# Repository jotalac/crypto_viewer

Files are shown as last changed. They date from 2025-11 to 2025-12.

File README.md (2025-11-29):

# Crypto Price Viewer
show show

DIY cryptocurrency price dispaly.

## Description

This project is diy simple **cryptocurrency price viewer**. It fetches real-time data from a cryptocurrency API and displays it on a screen. The device is housed in a 3D-printed case with colored screen.

This is a standalone device that is not dependent on your computer.

## Features

*   **Price Tracking:** Fetches and displays up-to-date cryptocurrency prices.
*   **Display:** Shows data on 240x320px screen.
*   **Button Controls:** Navigate through different cryptocurrencies.
*   **Buzzer:** Provides audible alerts.
*   **3D-Printed Case:** A custom-designed case to house all the components.
*   **Configurable from phone:** Connect to AP and configure the device from your phone.
*   **Wi-Fi Connectivity:** Connects to your local network to access the internet.

## Hardware

This project uses the following hardware components:

*   **Microcontroller:** XIAO ESP32C6
*   **Display:** 2inch 240x320px TFT Display: 
*   **Buttons:** 2x - 12x12mm tactile switch (B3F-4055)
*   **Buzzer (optional):** buzzer without generator
*   **Antenna (optional, for better signal):** mini antenna with uFL connector
*   **Perfboard:** prefboard 30x70 mm
*   **Cables and wires**
*   **3D printed case:** 3d printed parts, in the model folder
*   **Screws:** 2x 2.5x20mm screw (for case assembly)

#### Hardware links
- Dispaly (~3.0$)
    - https://www.aliexpress.com/item/1005006589727895.html?spm=a2g0o.order_list.order_list_main.11.757d1802qw4zkG
- Microcontroller (~8.0$, get from your local supplier)
    - https://botland.cz/moduly-wifi-a-bt-esp32/24783-seeed-xiao-esp32-c6-wifi-bluetooth-seeedstudio-113991254-5904422385705.html
- Tactile switches (~0.5$):
    - https://makershop.ie/B3F4055?srsltid=AfmBOooik3h_e8dq_zdSf28YTv6m92bTonL3PdaJR46RWWBAH6ENf9dU
- Buzzer (~2.0$):
    - https://botland.store/buzzers-sound-generators/4187-buzzer-without-generator-23mm-1-40v-in-a-case-5904422366070.html
- Antenna (~2$)
    - https://botland.store/wifi-antennas/13810-mini-flexible-wifi-antenna-24ghz-with-ufl-connector-100mm-5904422321505.html
- Perfboard (~0.5$)
    - https://www.amazon.com/Fielect-Electronic-Protoboard-Prototyping-Printed/dp/B081Q4XH7Z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
- 3D printed case
    - https://github.com/jotalac/crypto_viewer/tree/main/model

## Usage guide
### Setup
*   After first connection you will se this screen


*   Connect to that wifi from your phone, and this setup screen will popup
  


*   Select configue wifi
*   Select your wifi ssid and fill in the password
*   Below you can set up to 3 cryptocurrencies to be displayed on your display
*   Hit save

## Usage
*   Price refreshes once in 10 minutes for the currently displayed coin 
    *   you can chagne the interval in the code
    *   don't make the interval too short, because you might hit the rate limit of the api

*   **Left button press** - go to next coin
*   **Left button hold** - fetches new price, for the currently displayed coin
*   **Right button press** - reset the device
*   **Right button hold** - enter config mode

## Software

The firmware is written in C++ using the Arduino framework.

### Libraries

*   TFT_eSPI - by Bodmer
*   ArduinoHttpClient
*   ArduinoJson
*   WiFiManager
*   Preferences - by Volodymyr Shymanskyy

## Assembly Guide

### Step 1: Setup arduino ide
- add xiao esp32c6 support for the arduino ide
    - guide: https://wiki.seeedstudio.com/xiao_esp32c6_getting_started/
- downlaod listed libraries
- find this path on you computer: **Arduino/libraries/TFT_eSPI/User_Setup.h**
    - paste this to the user setup file:
    ```bash
    #define USER_SETUP_INFO "User_Setup"
    #define ST7789_2_DRIVER
    #define TFT_SDA_READ   
    #define TFT_RGB_ORDER TFT_RGB  // Colour order Red-Green-Blue

    #define TFT_WIDTH  240 
    #define TFT_HEIGHT 320

    #define TFT_MOSI 18  
    #define TFT_SCLK 19  
    #define TFT_CS   22  
    #define TFT_DC   21  
    #define TFT_RST  23  

    #define LOAD_GLCD   // Font 1. Original Adafruit 8 pixel font needs ~1820 bytes in FLASH
    #define LOAD_FONT2  // Font 2. Small 16 pixel high font, needs ~3534 bytes in FLASH, 96 characters
    #define LOAD_FONT4  // Font 4. Medium 26 pixel high font, needs ~5848 bytes in FLASH, 96 characters
    #define LOAD_FONT6  // Font 6. Large 48 pixel font, needs ~2666 bytes in FLASH, only characters 1234567890:-.apm
    #define LOAD_FONT7  // Font 7. 7 segment 48 pixel font, needs ~2438 bytes in FLASH, only characters 1234567890:-.
    #define LOAD_FONT8  // Font 8. Large 75 pixel font needs ~3256 bytes in FLASH, only characters 1234567890:-.
    #define LOAD_GFXFF  // FreeFonts. Include access to the 48 Adafruit_GFX free fonts FF1 to FF48 and custom fonts
    #define SMOOTH_FONT

    #define SPI_FREQUENCY  27000000
    #define SPI_READ_FREQUENCY  20000000
    #define SPI_TOUCH_FREQUENCY  2500000
    ``` 
### Step 2: Soldering components 
*   Solder controller on the prefboard (9 pins availible left, 8 pin availible on right)
*   Solder display
*   Solder buzzer
*   Put the antenna on the controller port
*   Don't solder the buttons just yet

*  *solder the components according to the wiring diagram and tables*

### Wiring

diagram
diagram2

**Display**

| From (Display) | To (ESP32C6) |
| --- | --- |
| GND | GND |
| VCC | 3V3 |
| SCL | D8 (GPIO19) |
| SDA | D10 (GPIO18) |
| RST | D5 (GPIO23) |
| DC |  D3 (GPIO21) |
| CS |  D4 (GPIO22) |

**Buttons**
- leg orientation doesnt matter (but make sure to solder the opposite legs)

| From (Button) | To (ESP32C6) |
| --- | --- |
| left btn - 1. leg | D1 (GPIO1) |
| left btn - 2. leg | GND |
| |  |
| right btn - 1. leg | D2 (GPIO2) |
| right btn - 2. leg | GND |

**Buzzer**

| From (Buzzer) | To (ESP32C6) |
| --- | --- |
| red cable | D0 (GPIO0) |
| black cable | GND |

### Step 3: 3D Printing

*   Print the case and button caps
*   You can choose the version with holes (much cooler) or the normal one without holes

### Step 4: Final Assembly

*   Put the buttons with caps into the holes on top of the case
*   Now solder the buttons according to the prefboard according to the diagram   
*   Slide the prefboard into the case and put in the antenna and buzzer
*   Put in the 2 screws to hold the two parts of the case together

### Step 5: Software flashing

*   Connect the board to your pc
*   Clone this repository
*   In Arduino IDE open the `code.ino` file
*   Make sure you have installed all the libraries and edited the `User_Setup.h` file
*   Click the upload button in the arduino ide to compile and flash the firmware
    * The ide might tell you that you have run out of memeory on the board
        *   go to: `Tools->Partition Scheme` and select `Huge APP`

## Contributing

- Contributions are welcome! Please feel free to submit a pull request.
- Adding new features is very welcome.

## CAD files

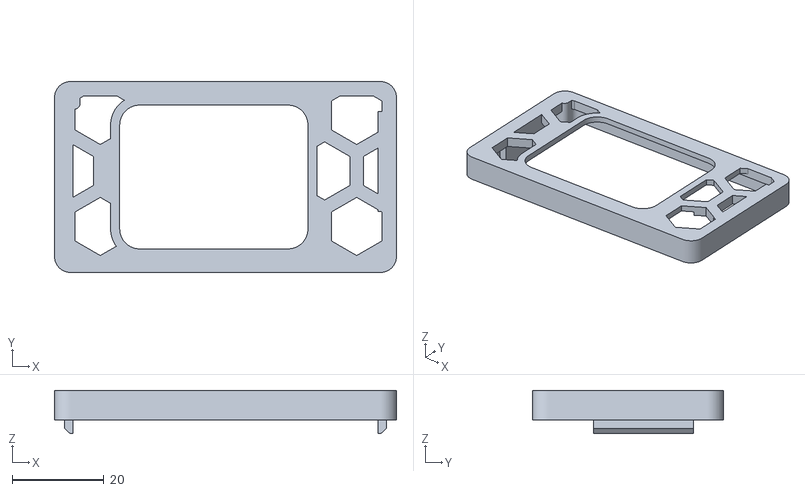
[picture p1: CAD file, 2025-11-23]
model/holes/front-holes.stl
74.7 x 41.7 x 9.50

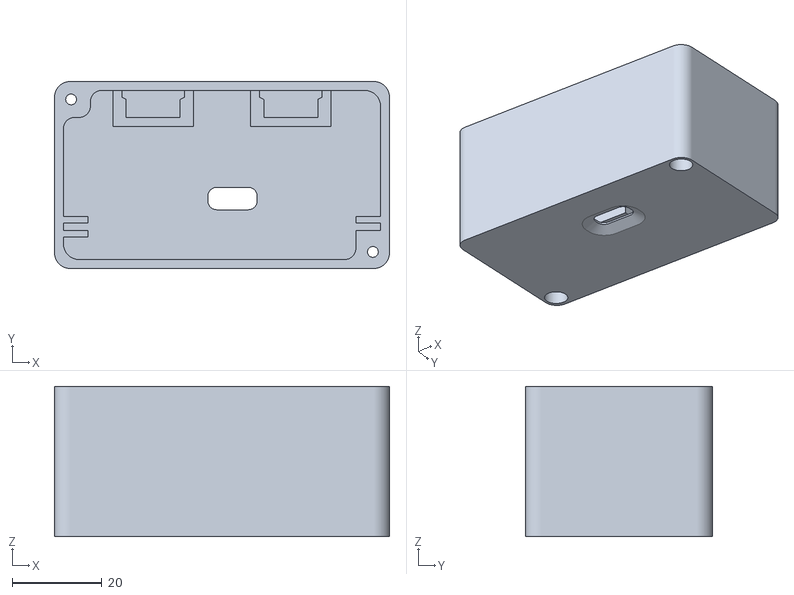
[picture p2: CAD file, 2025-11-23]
model/normal/back.stl
74.7 x 41.7 x 33.5

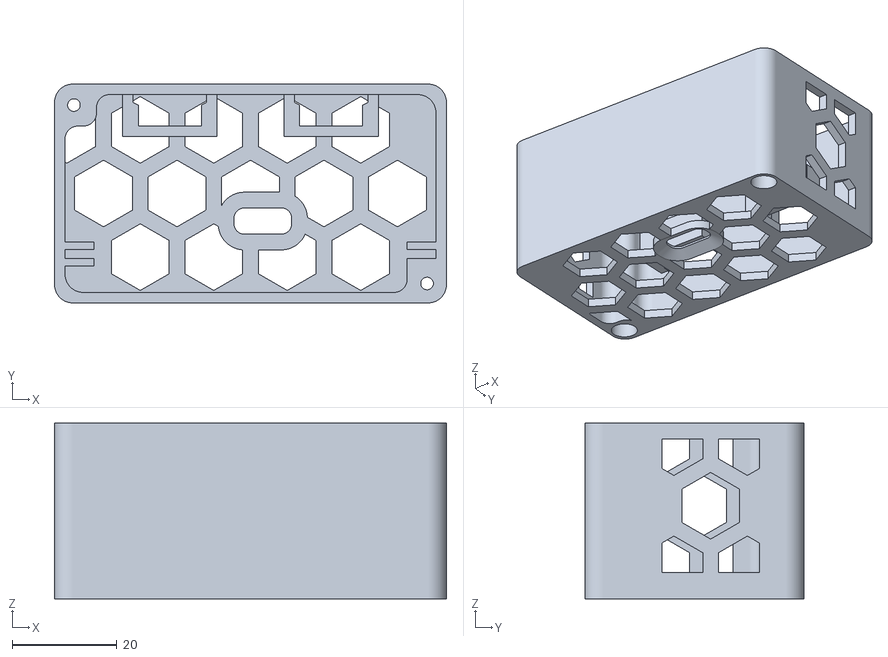
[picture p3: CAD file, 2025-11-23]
model/holes/back-holes.stl
74.7 x 41.7 x 33.5

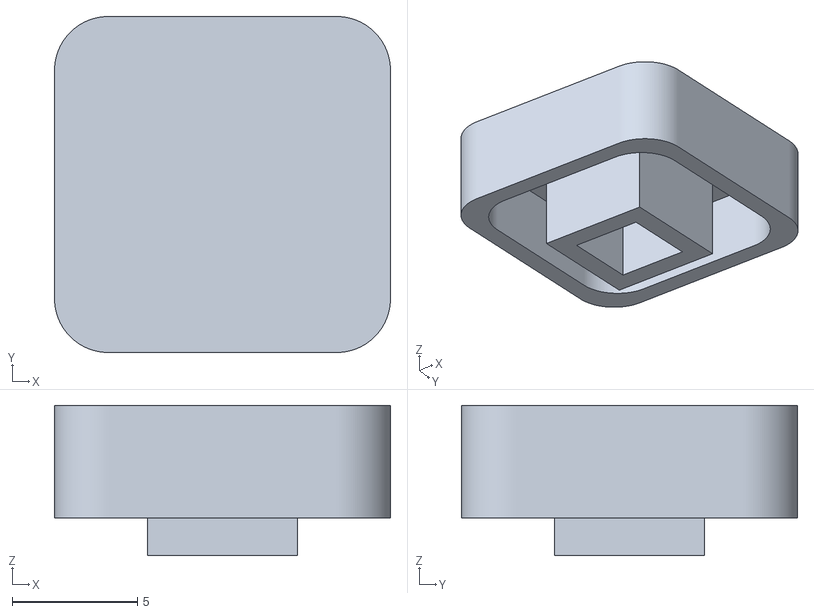
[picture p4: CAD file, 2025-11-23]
model/normal/button-simple.stl
13.4 x 13.4 x 6.00

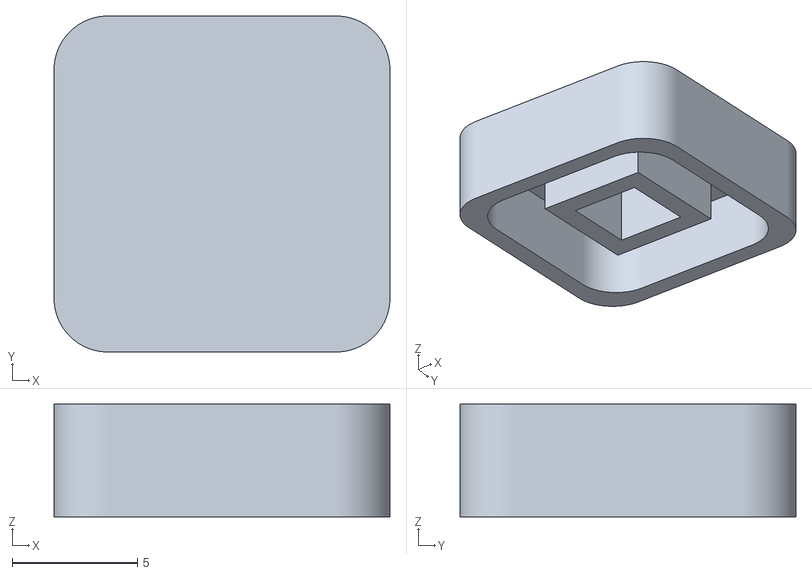
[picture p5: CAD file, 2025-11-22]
model/holes/button-simple.stl
13.4 x 13.4 x 4.50

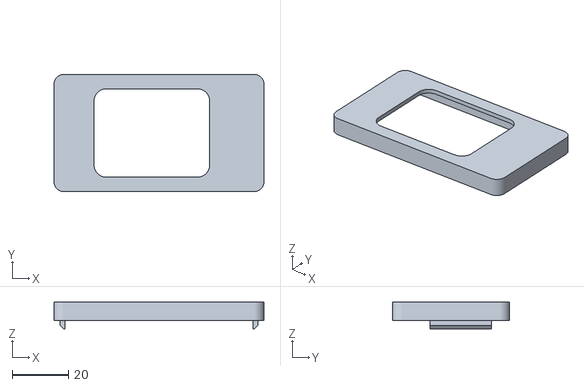
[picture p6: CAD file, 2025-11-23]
model/normal/front.stl
74.7 x 41.7 x 9.50

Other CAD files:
model/step/front.step
model/step/back.step

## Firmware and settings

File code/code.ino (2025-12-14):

#include "config.h"
#include "wifi_config.h"
#include "network.h"
#include "display.h"
#include "utils.h"
#include "buzzer.h"
#include "button_control.h"

unsigned long last_fetch_time = 0;
const unsigned long FETCH_INTERVAL = 1000 * 60 * 10;  // 10 minutes
const unsigned long FETCH_GRAPH_INTERVAL = 1000 * 60 * 60;  // 1 hour
CoinData all_coins_data[3] = {{}, {}, {}};
GraphData all_graph_data[3] = {{}, {}, {}};
int total_screens = 0;

void setup() {
  Serial.begin(9600);

  total_screens = get_screen_count();

  // setup buttons and anthena  pins
  pinMode(BUTTON_COIN_PIN, INPUT_PULLUP);
  pinMode(BUTTON_CONFIG_PIN, INPUT_PULLUP);
  pinMode(BUZZER_PIN, OUTPUT);

  turn_on_external_antenna();

  tft.init();
  tft.setRotation(1);
  tft.setSwapBytes(true);
  
  //setup wifi
  display_message("Connecting...");
  //play boot sound
  play_startup_sound();


  if (!setup_wifi_manager()) {
    display_message("Wifi connection failed");
    delay(2000);
    ESP.restart();
  }

  display_message("Getting current time...");
  setup_time();
}
 
void loop() {  
  //check all button presses
  check_btn_1_press();
  check_btn1_hold();

  check_btn2_press();
  check_btn2_hold();

  //update time;
  events();

  int current_index = get_current_screen_index();

  if (current_index >= total_screens - 1) {
    render_screen_clock();
  }
  else {
    //check if we should fetch new data
    unsigned long current_time = millis();
    if (current_time - last_fetch_time >= FETCH_INTERVAL || last_fetch_time == 0) {
      Serial.println("Fetching new price...");
  
      //check if wifi is connected
      if (!check_wifi_connection()) {
        display_message("Wifi reconnect failed, Restarting...");
        delay(2000);
        ESP.restart();
      };
  
      int current_coin_index = get_current_screen_index();
  
      //fetch coin data
      CoinData fetched_data = fetch_coin_data();
  
      //check if we need to fetch new grapth (every 1 hour)
      GraphData graph_data = all_graph_data[current_coin_index]; 
      if ((current_time - graph_data.last_fetch >= FETCH_GRAPH_INTERVAL || graph_data.last_fetch == 0) && should_display_graph()) {
        graph_data = fetch_graph_data();
        all_graph_data[current_coin_index] = graph_data;
      }
  
      if (fetched_data.price != -1) {
        //display new data
        render_screen(fetched_data, graph_data, "*24h");
        last_fetch_time = current_time;
        //update the saved vlaues
        all_coins_data[current_coin_index] = fetched_data;
        //play sound if the current price is ath
        if (fetched_data.ath_percentage >= 0) play_ath_sound();
      } else {
        display_message("Fetch error for: " + get_coin_name());
        // Retry in 30 seconds instead of 10 minutes on error
        last_fetch_time = current_time - FETCH_INTERVAL + 30000;
      }
    }
  }

  delay(100);
}

void check_btn_1_press() {
  if (check_screen_change_button()) {    
      //try to go to next coin if only one coin is setup dont do anything
      if (go_to_next_screen()) {
        Serial.println("Cycling to next screen");  
        
        int current_index = get_current_screen_index();
        
        // Determine name for display
        String name_to_show;
        if (current_index >= total_screens - 1) {
            name_to_show = "Time";
        } else {
            name_to_show = get_coin_name();
        }

        display_message("Switching to: " + name_to_show);
        delay(500);
        
        if (current_index >= total_screens - 1) {
          //display time
          render_screen_clock();
        }
        // Force immediate fetch for coins
        else {
           // If we have no data yet, force fetch
           if (all_coins_data[current_index].symbol.empty()) {
             last_fetch_time = 0;
           } else {
             render_screen(all_coins_data[current_index], all_graph_data[current_index], "*24h");
           }
        }
      }
  }
}

void check_btn1_hold() {
  if (check_coin_fetch_button()) {    
    Serial.println("Fetching new price");
    display_message("Fetching new price");    
    // Force immediate fetch
    last_fetch_time = 0;
  }
}

void check_btn2_press() {
  if (check_reset_button()) {
    Serial.println("Reseting button pressed");

    display_message("Reseting device");
    delay(1000);
    ESP.restart();
  }
}

void check_btn2_hold() {
  if (check_config_button()) {
    Serial.println("Config mode entered");
    play_config_sound();

    display_wifi_setup_message("Configue");

    if (start_config_portal_on_demand()) {
      display_message("Config saved, restarting...");
      delay(2000);
      ESP.restart(); //restart to apply changes
    } else {
      display_message("Config canceled");
      last_fetch_time = 0; //fetch imidietly
    }
  }
}

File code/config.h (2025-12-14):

#ifndef CONFIG_H
#define CONFIG_H

#include <Arduino.h>
#include <WiFi.h>
#include <WebServer.h>
#include <WiFiManager.h>
#include <HTTPClient.h>
#include <ArduinoJson.h>
#include <Preferences.h>
#include <TFT_eSPI.h>
#include <ezTime.h>
#include <vector>
#include <string>
#include <cstdio>

// extern variables
extern Preferences preferences; 
extern TFT_eSPI tft;
extern Timezone myTZ;

// button
#define PORTAL_TIMEOUT 120 // 2 minutes wait in wifi config mode
#define CONFIG_PRESS_TIME 3000
#define BUTTON_SHORT_PRESS_TIME 50

#define BUTTON_COIN_PIN 1
#define BUTTON_CONFIG_PIN 2

//buzzer
#define BUZZER_PIN 0

//coin cycling
#define MAX_COINS 3

#endif

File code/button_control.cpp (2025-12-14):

#include "config.h"
#include "button_control.h"

//check if button is hold for 3 seconds
bool check_config_button() {
    static unsigned long button_press_start = 0;
    static bool button_was_pressed = false;
    
    bool button_pressed = (digitalRead(BUTTON_CONFIG_PIN) == LOW);
    
    if (button_pressed && !button_was_pressed) {
        // Button just pressed
        button_press_start = millis();
        button_was_pressed = true;
    } 
    else if (!button_pressed && button_was_pressed) {
        // Button released
        button_was_pressed = false;
        button_press_start = 0;
    }
    else if (button_pressed && button_was_pressed) {
        // Button is being held
        unsigned long hold_time = millis() - button_press_start;
        if (hold_time >= CONFIG_PRESS_TIME) {
            button_was_pressed = false;
            button_press_start = 0;
            return true;  // Button held long enough
        }
    }
    
    return false;
}

bool check_reset_button() {
    static unsigned long button_press_start = 0;
    static bool button_was_pressed = false;
    
    bool button_pressed = (digitalRead(BUTTON_CONFIG_PIN) == LOW);
    
    if (button_pressed && !button_was_pressed) {
        button_press_start = millis();
        button_was_pressed = true;
    } 
    else if (!button_pressed && button_was_pressed) {
        // Button released - check duration
        unsigned long hold_time = millis() - button_press_start;
        button_was_pressed = false;
        button_press_start = 0;
        
        // Short press (less than config time)
        if (hold_time >= BUTTON_SHORT_PRESS_TIME && hold_time < CONFIG_PRESS_TIME) {
            return true;
        }
    }
    
    return false;
}



bool check_screen_change_button() {
    static unsigned long button_press_start = 0;
    static bool button_was_pressed = false;
    
    bool button_pressed = (digitalRead(BUTTON_COIN_PIN) == LOW);
    
    if (button_pressed && !button_was_pressed) {
        button_press_start = millis();
        button_was_pressed = true;
    } 
    else if (!button_pressed && button_was_pressed) {
        // Button released - check duration
        unsigned long hold_time = millis() - button_press_start;
        button_was_pressed = false;
        button_press_start = 0;
        
        // Short press (less than config time)
        if (hold_time >= BUTTON_SHORT_PRESS_TIME && hold_time < CONFIG_PRESS_TIME) {
            return true;
        }
    }
    
    return false;
}

bool check_coin_fetch_button() {
    static unsigned long button_press_start = 0;
    static bool button_was_pressed = false;
    
    bool button_pressed = (digitalRead(BUTTON_COIN_PIN) == LOW);
    
    if (button_pressed && !button_was_pressed) {
        // Button just pressed
        button_press_start = millis();
        button_was_pressed = true;
    } 
    else if (!button_pressed && button_was_pressed) {
        // Button released
        button_was_pressed = false;
        button_press_start = 0;
    }
    else if (button_pressed && button_was_pressed) {
        // Button is being held
        unsigned long hold_time = millis() - button_press_start;
        if (hold_time >= CONFIG_PRESS_TIME) {
            button_was_pressed = false;
            button_press_start = 0;
            return true;  // Button held long enough
        }
    }
    
    return false;
}

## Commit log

2025-11-15 adding antenna support
2025-11-22 adding model
    [back-holes.stl, back.stl, button-simple.stl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]
2025-11-22 sample readme
2025-11-23 updating models
    [back-holes.stl, back.step, back.stl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]
